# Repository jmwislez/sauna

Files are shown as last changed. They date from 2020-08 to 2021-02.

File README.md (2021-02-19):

# Building an outside sauna from scratch

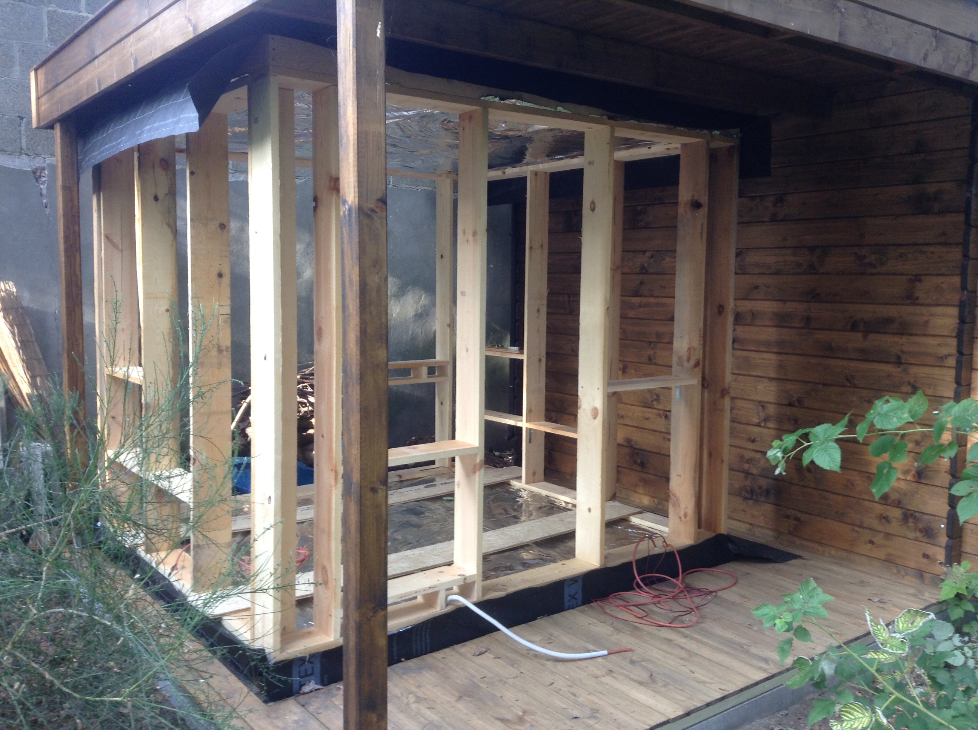
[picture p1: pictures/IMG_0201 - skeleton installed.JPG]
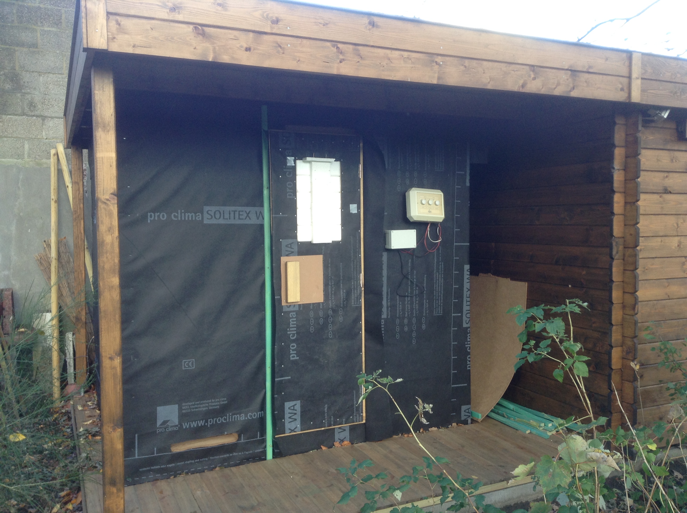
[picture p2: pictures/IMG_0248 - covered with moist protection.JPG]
  

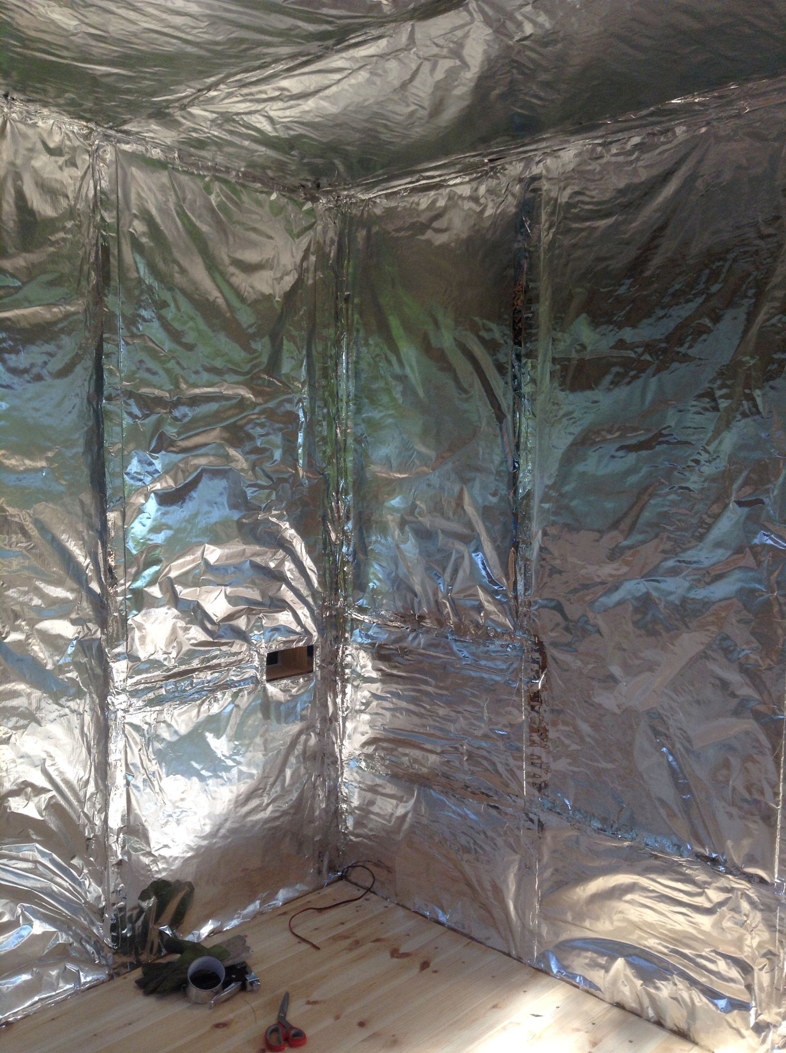
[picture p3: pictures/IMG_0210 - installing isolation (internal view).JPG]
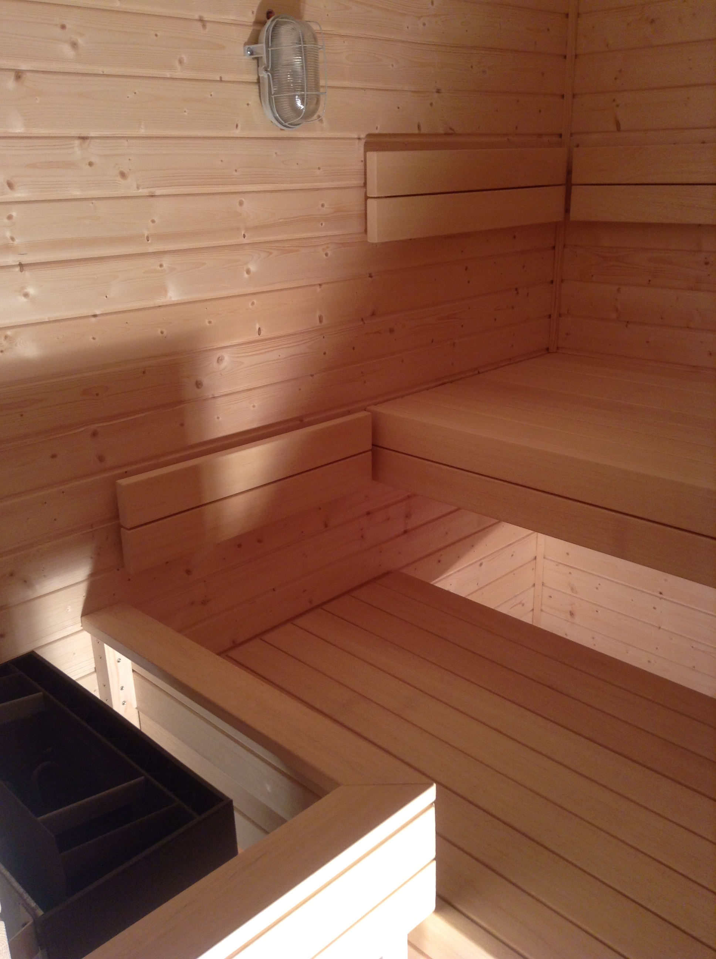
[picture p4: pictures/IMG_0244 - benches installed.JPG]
  

## What this repository provides

In this repository, you'll find a 3D design (FreeCAD) for an external sauna I built in 2013, as well as for an outside shower I added recently.  It also provides some materials and costs overviews for the sauna (2013 in Belgium), as well as snapshots of the design and pictures taken during building.  Through cost-effective procurement, I was able to limit the material costs to about 2000 euro.

## The layout and dimensions

The sauna was to be installed outside, under an existing 2.2m high 3x3m hood of a garden shed.  Hence, there is no roof as part of the sauna design. A stabilized platform was already available.  

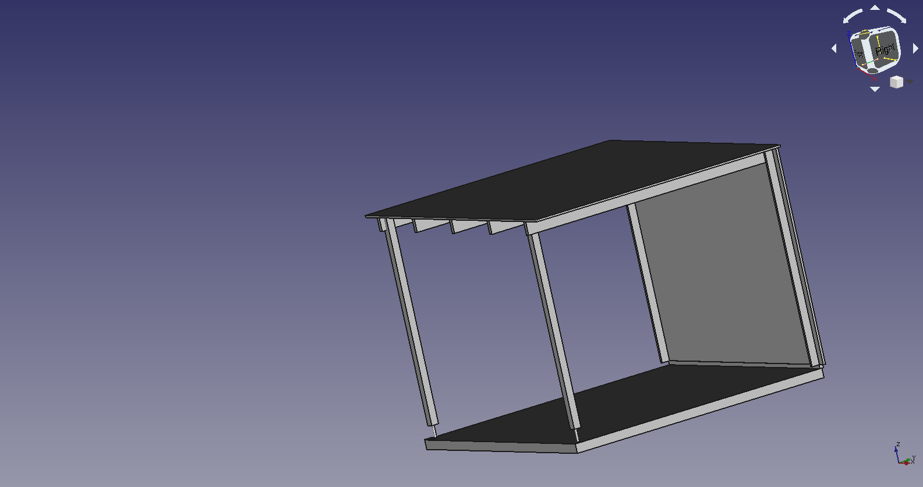
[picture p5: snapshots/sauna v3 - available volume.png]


The available volume under the hood was the main driving factor for the dimensions.  Within these limitations, I searched for an optimal layout with minimal inner dimensions (to reduce the volume and hence heating costs), and considering anthropometric dimensional data (95th percentile) for ergonomy.  The sizes were then fine-tuned to the available wood and materials sizes.  I am quite satisfied with the selected layout, as the sauna is comfortable and makes good use of the available space.

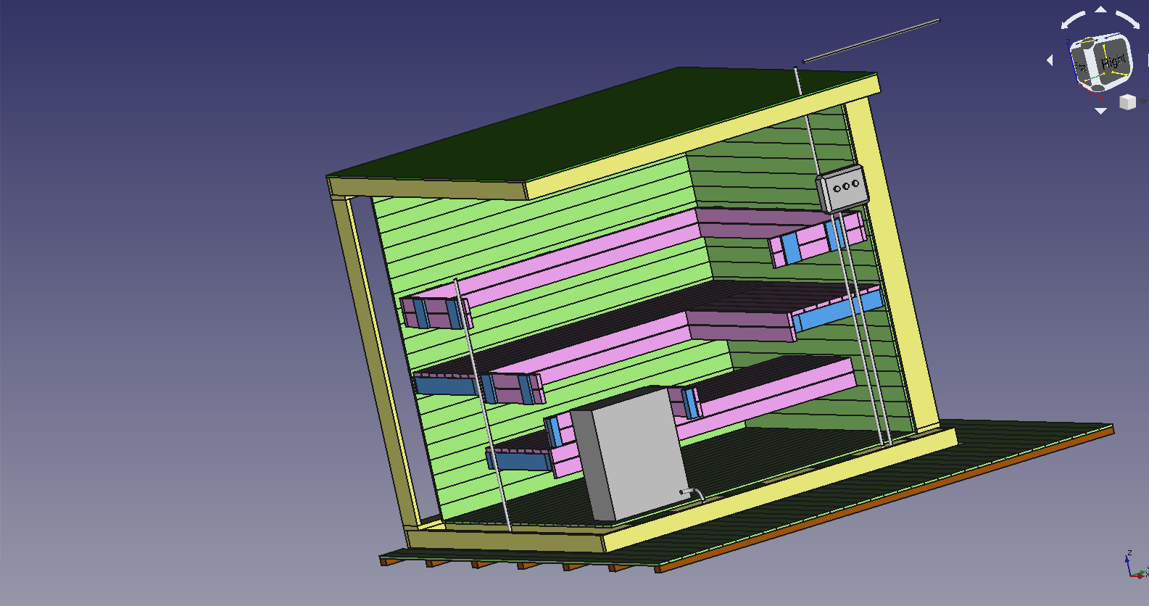
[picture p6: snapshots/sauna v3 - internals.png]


For the height, this meant one bench at 42cm height above the sauna floor (typical ergonomic sitting height), one at 84cm (to sit with feet on the lower bench), and then a sitting height of at least 100cm (95th percentile) between the top bench and the roof - I ended up at 104cm.  Given the limitation in the vertical space, I had to limit the floor and ceiling isolation thickness to 10cm only.  Total external height is 213cm, total internal height is 188cm.

For the internal width, I took 2m lying length (95th percentile), and for the depth 1.8m (50th percentile, and fine for me), which conveniently allowed me to have 3 standard-sized segments in both side walls.  What I forgot is to consider that two persons lying down will collide in the corner.  Hence, if you have room, take some extra margin.

The sauna is resting on the base beams of the terrace, to allow for air to circulate in the cavity in the walls, in order to keep them dry.

## Construction

The construction is based on a wood skeleton, with 58cm in between the beams (for fitting 60cm rockwool).  

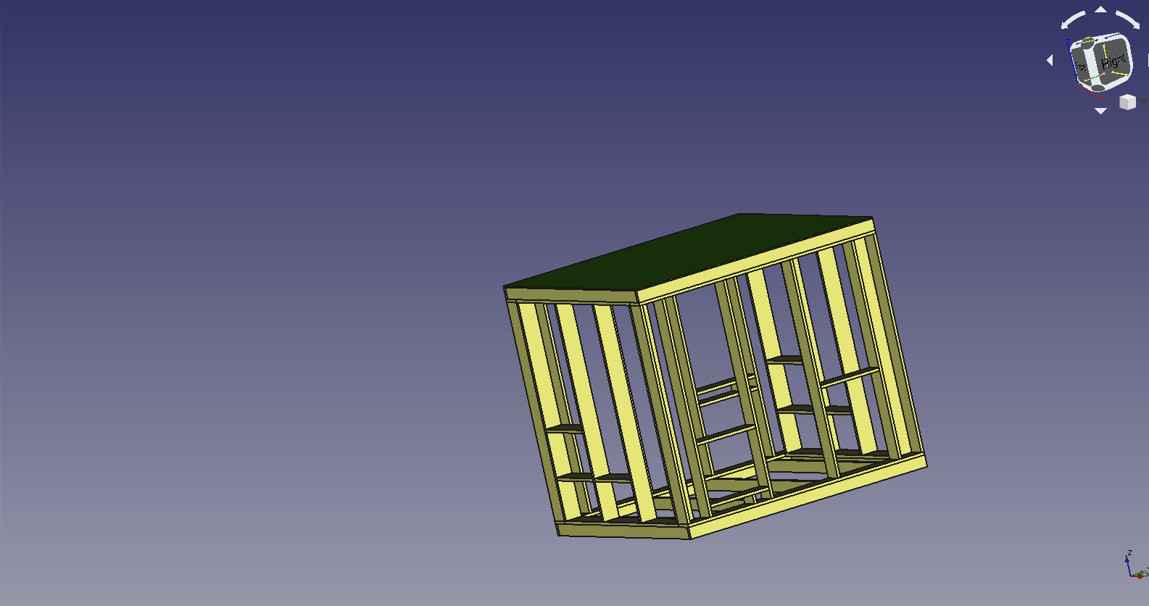
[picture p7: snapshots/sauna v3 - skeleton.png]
 
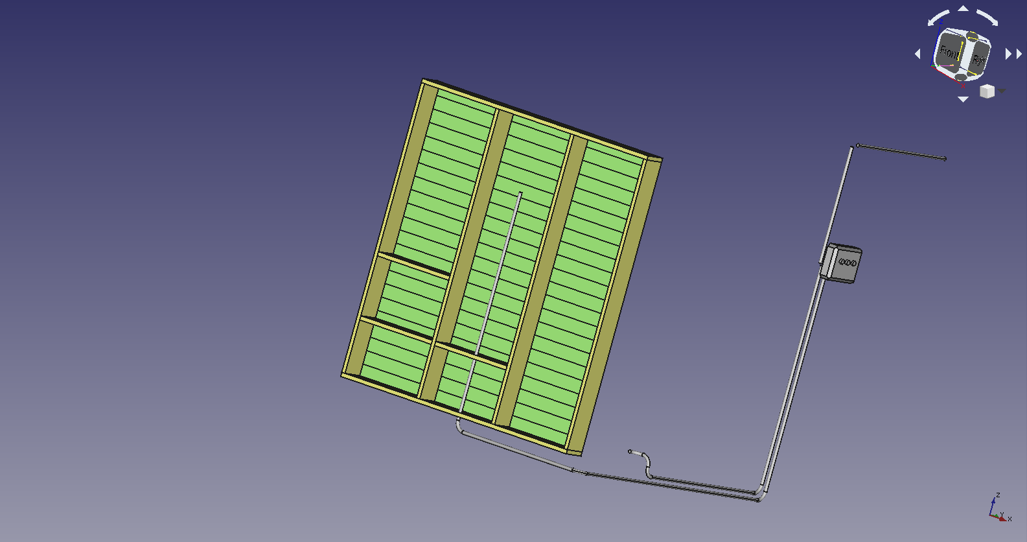
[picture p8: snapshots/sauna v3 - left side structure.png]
 
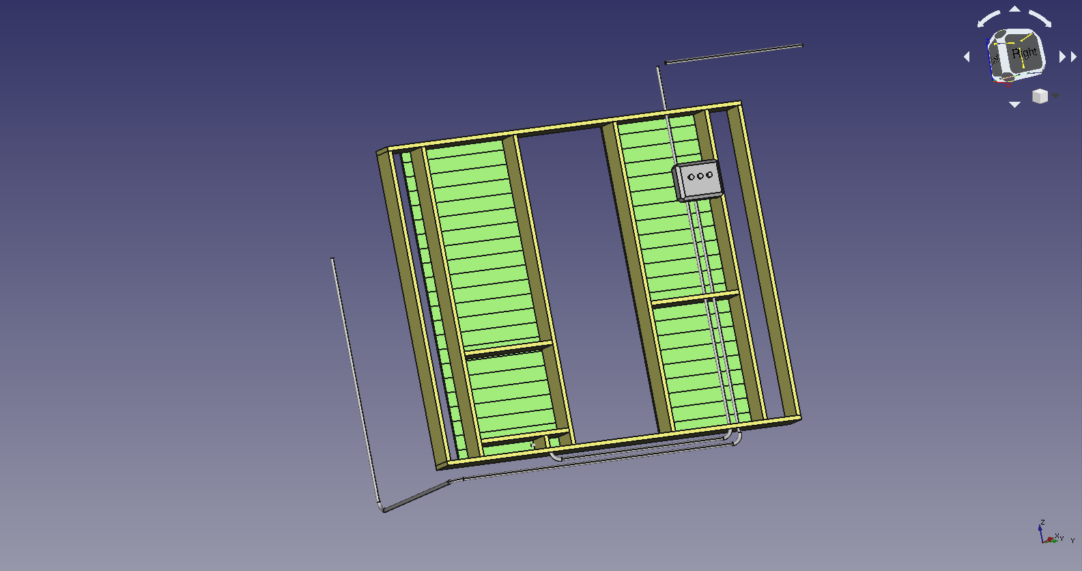
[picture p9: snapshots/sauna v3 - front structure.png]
 
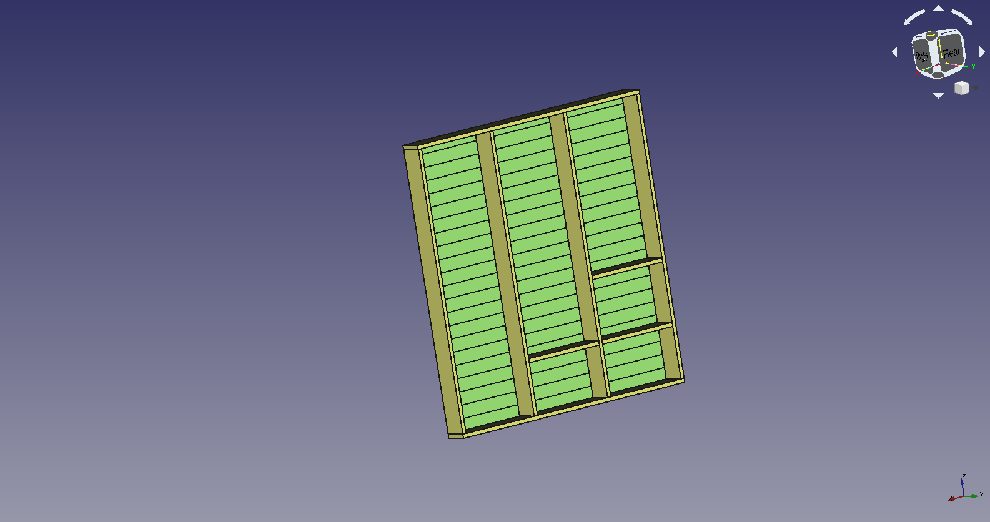
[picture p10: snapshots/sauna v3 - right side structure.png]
 
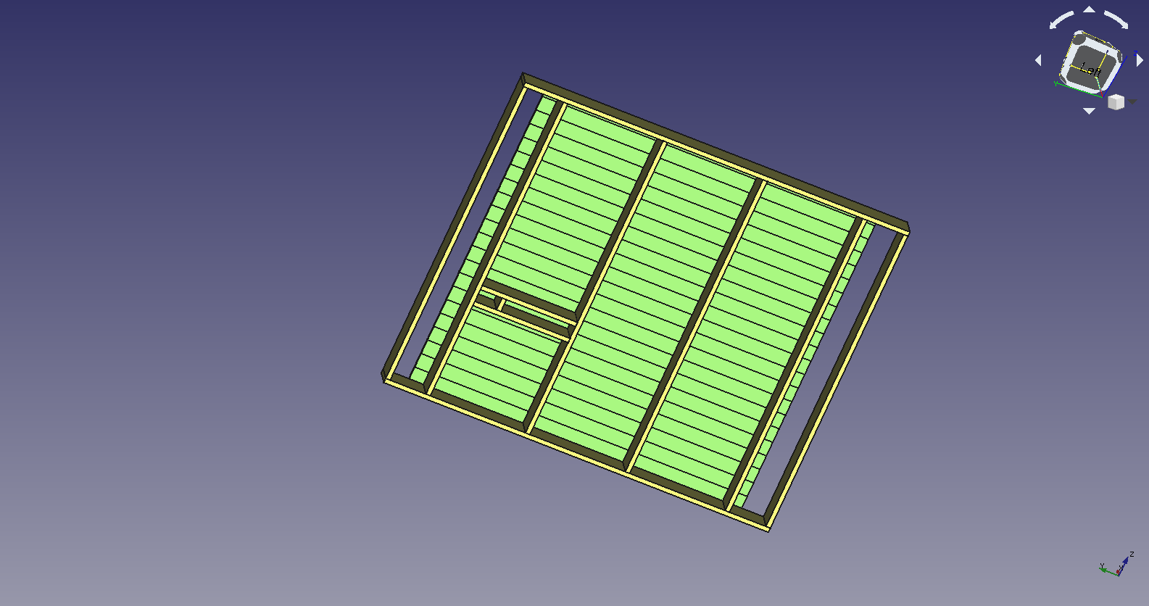
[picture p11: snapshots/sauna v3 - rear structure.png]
 
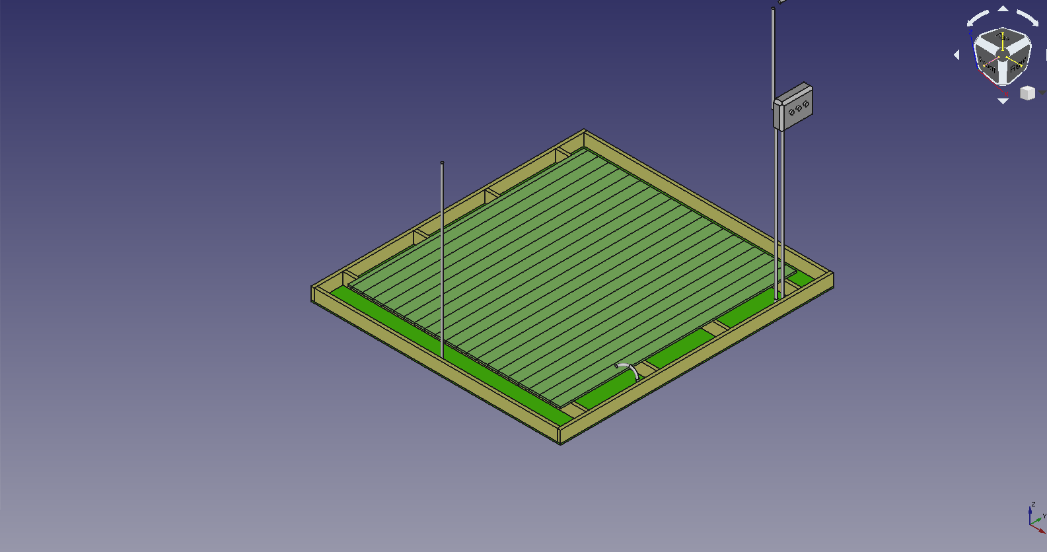
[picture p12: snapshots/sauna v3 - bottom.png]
 
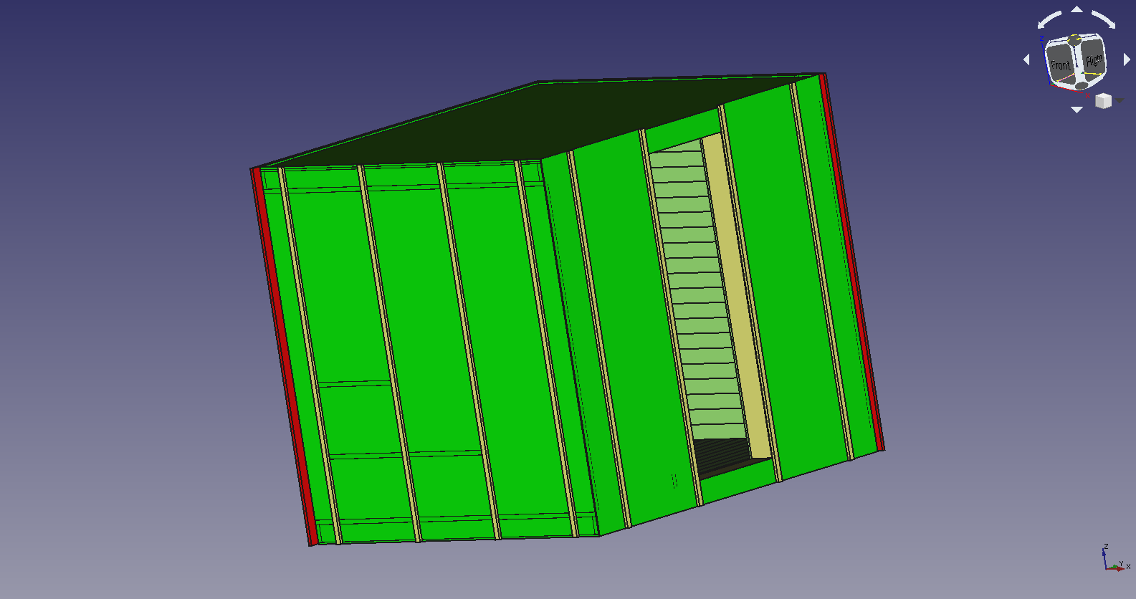
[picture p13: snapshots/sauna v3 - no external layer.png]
 
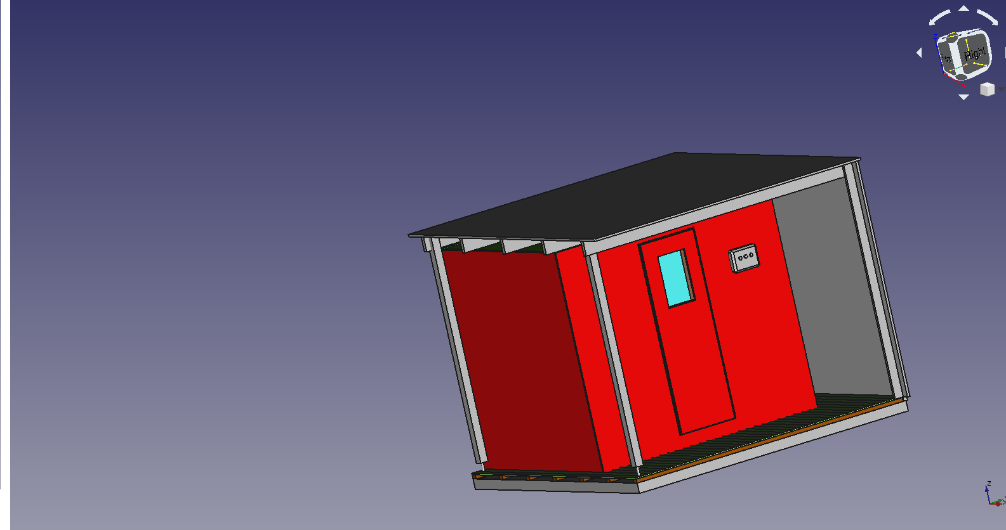
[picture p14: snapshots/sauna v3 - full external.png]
 

This was roughly the manufacturing and assembly sequence:
* Assembly of the terrace, with 7 parallel base beams, and tongue-and-groove planks around the area where the sauna will be installed (all treated with Xyladecor).
* Covering the area of where the sauna will be with 1cmx1cm chicken wire, against mice.
* In a workshop, assembly of the skeletons for all 6 faces of the sauna.
* In the workshop, full outfitting of the bottom and top skeletons with OSB plates, electrical tubing and wiring, and rockwool with reflective vapourshield. Also mounting of the vapour permeable breathable membrane on all wood sides.
* Positioning of the bottom assembly onto the terrace.
* Installation of the skeletons of the side walls.
* Installation of the top assembly onto the side walls.
* Oufitting of the side walls with rockwool, making the vapourshield airtight with aluminium tape (to the extent possible).
* Installation of electricity tubing and wiring in the side walls.
* Closing the side walls with MDF plates, being mindful of the external connections that need to be made (to sauna controller and audio amplifier).
* Wrapping the vapour permeable breathable membrane around the side walls, and fully attaching it with staples.
* Installing the floor wood, as wel as the inner walls (nordic pine sauna-wood - attached with mounting clips), being mindful of the internal connections that need to be made (to light, heater, heat sensor and speakers).
* Installing the skeletons for the benches.
* Installing the heater, sensor, and controller.
* Installing the abachi wood for the benches and backrests, and the heater protection.
* Installing the door (assembled in workshop).
* First heat for the sauna! :-)
* Installing the slating battens and the external wood finishing (treated with Xyladecor).

The walls are composed of the following layers (from inside to outside), totalling 21cm:
* Internal wood finishing, composed of 95mm x 14mm tongue-and-groove planks [NL: saunaschroten] (second choice nordic spruce, specially dried for use in sauna), attached with mounting clips [NL: profielhoutklemmen].
* Reflective vapourshield (integrated with the glasswool), finished with aluminium tape.
* 60cm wide 15cm thick glasswool (Isover) with integrated reflective vapourshield, carried by the wood skeleton.
* Thin MDF plates for covering the glasswool.
* Vapour permeable breathable membrane [NL: dampscherm] (Pro Clima SOLITEX WA).
* Air layer (slating battens as spacers [NL: panlatten]).
* External wood finishing, composed of second choice 170mm x 19mm tongue-and-groove planks [NL: schroten], treated for outdoor use with Xyladecor.

Just to be clear: these are the layers of the floor, from inside to outside: wooden floor, moist shield, rockwool, OSB, vapour breathing membrane, chicken wire, air, and then the concrete base of the garden shed. Same for the roof, where the vapour breathing membrane was mounted in tent shape under the roof of the garden shed, to deal with possible leakages in the garden shed roof.

The layer build-up is also visible in the building pictures.

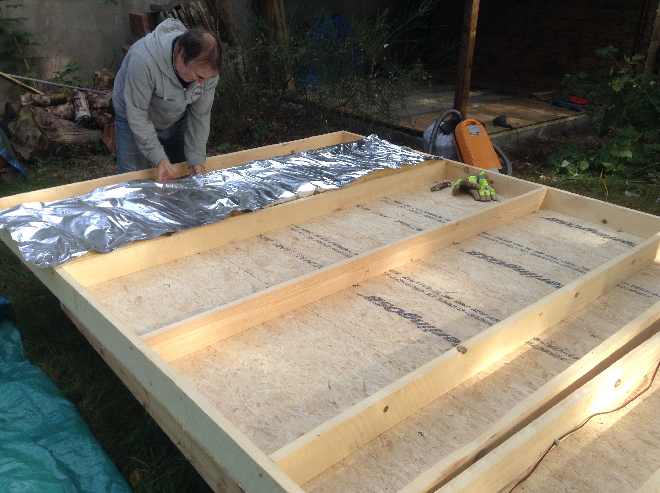
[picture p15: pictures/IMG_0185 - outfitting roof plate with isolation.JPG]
 
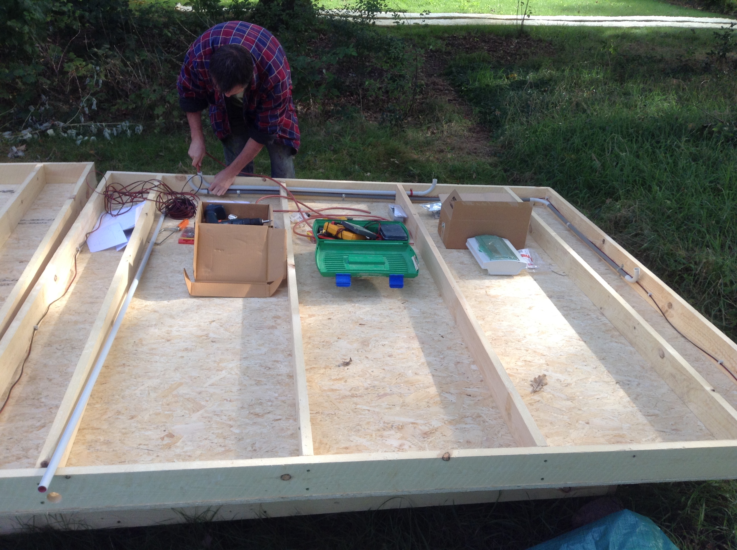
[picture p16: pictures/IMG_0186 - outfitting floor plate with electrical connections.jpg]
 
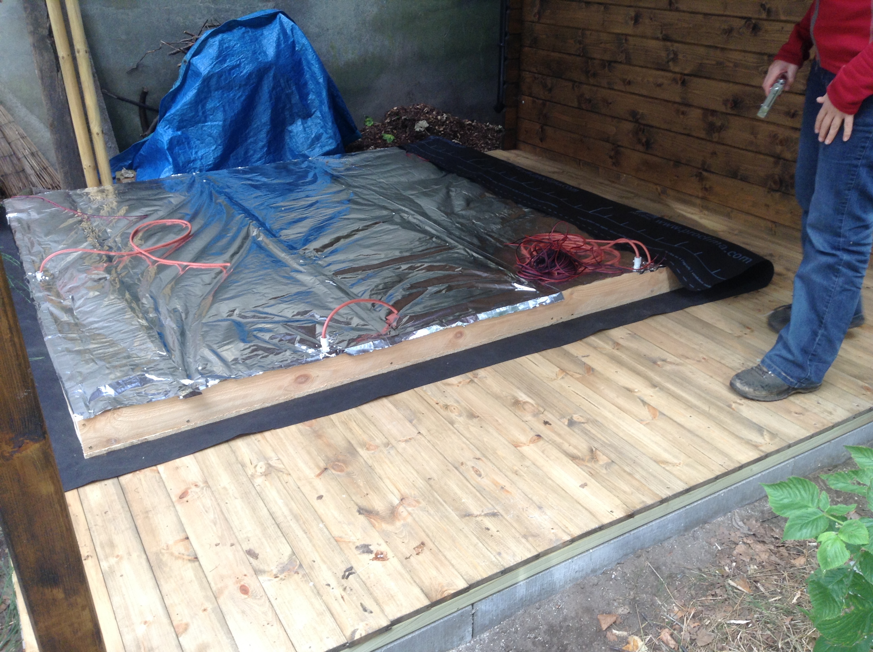
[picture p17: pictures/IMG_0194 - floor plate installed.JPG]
 
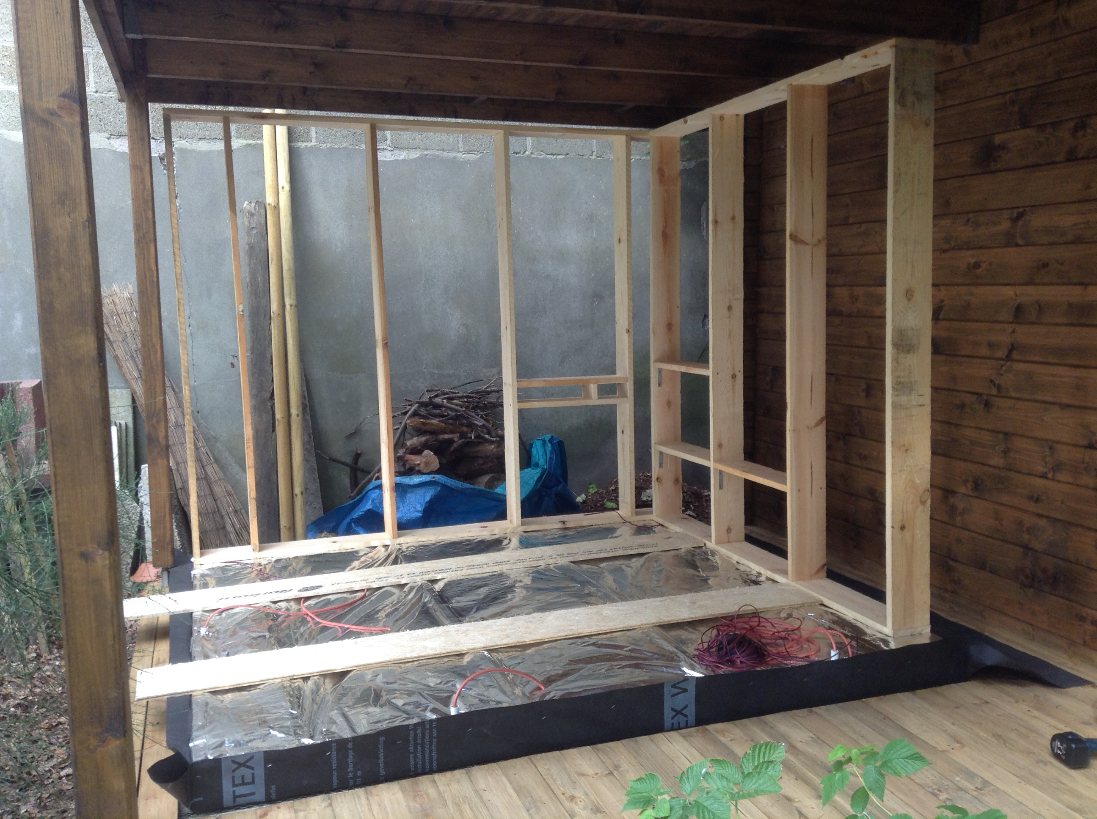
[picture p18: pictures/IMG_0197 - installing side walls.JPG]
 
 
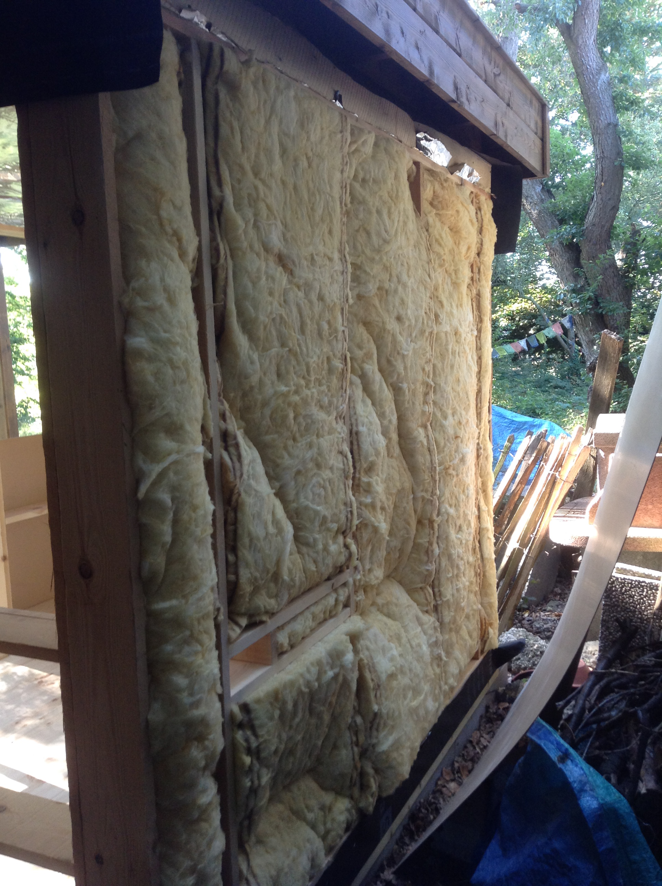
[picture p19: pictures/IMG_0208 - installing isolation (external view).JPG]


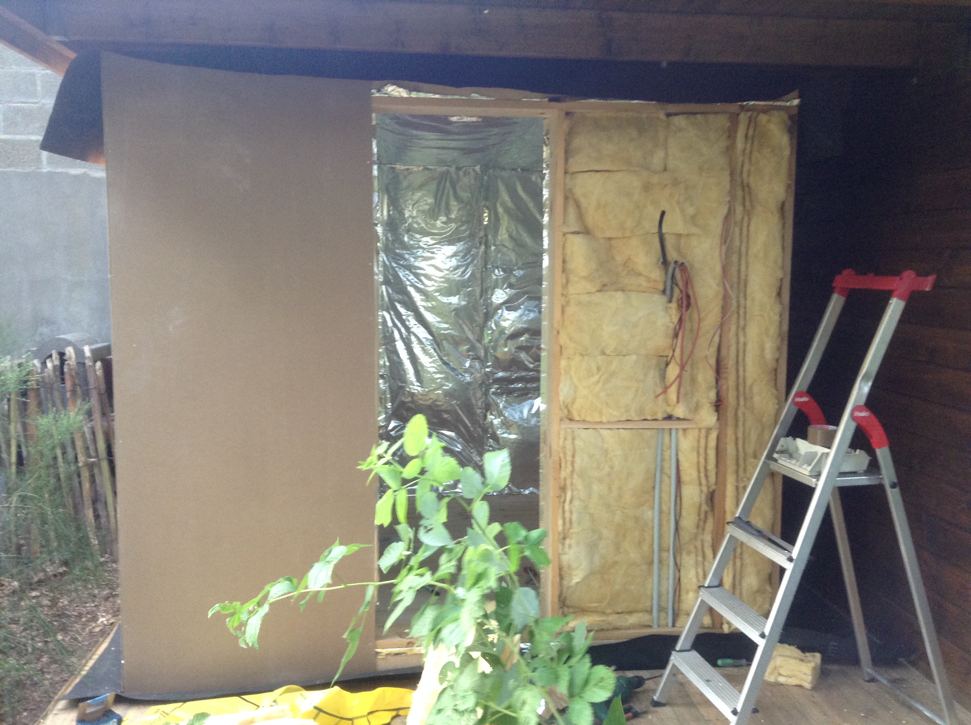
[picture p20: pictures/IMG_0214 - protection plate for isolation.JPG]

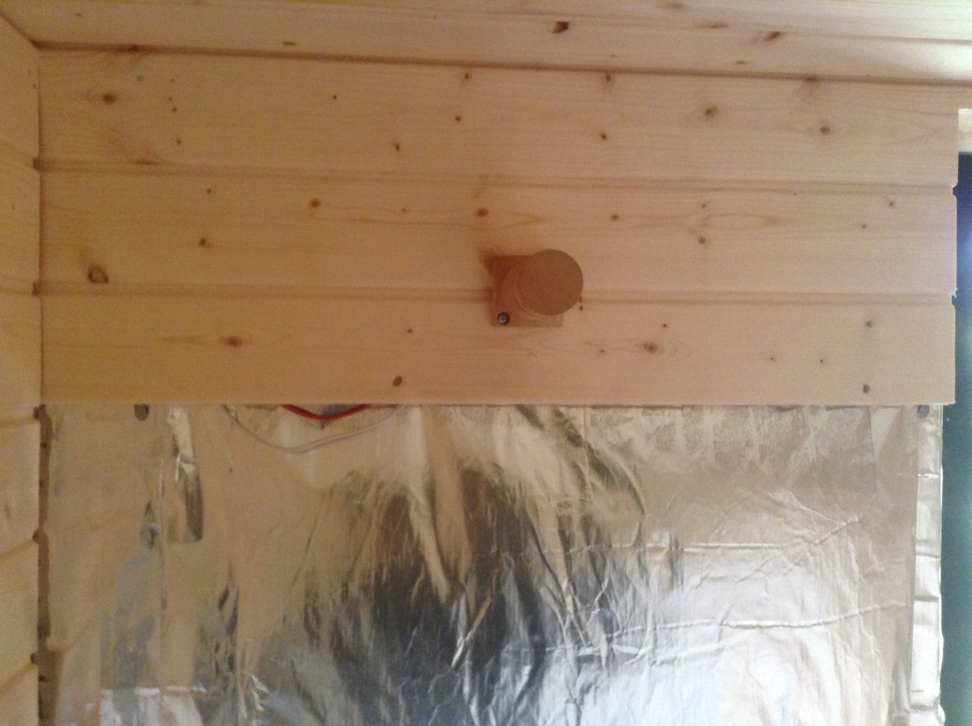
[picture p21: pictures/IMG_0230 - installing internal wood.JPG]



## Benches 

The benches are based on solid beams anchored to the main skeleton structure using big screws.  The benches are made of Abachi-wood.  This is an excellent choice, but be careful when working that wood: it generates a very fine dust which gives headaches that last for days.  Work outside, or with a good dust mask.

While 60cm width is enough for lying down, benches of 70cm are more comfortable. But for sitting down on a bench, 60cm is more comfortable than 70cm. This, and to limit the depth of the sauna, is why the lower bench extends 10cm under the top bench, and why the side bench is 60cm wide. 

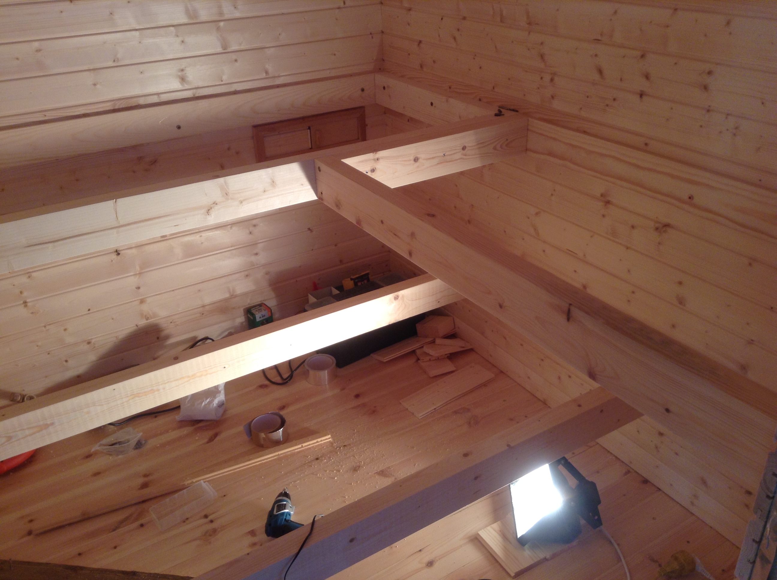
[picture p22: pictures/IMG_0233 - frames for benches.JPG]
 


## Door

TBW

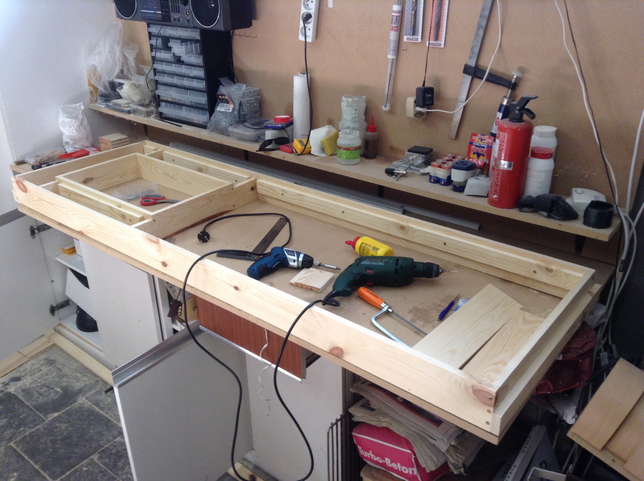
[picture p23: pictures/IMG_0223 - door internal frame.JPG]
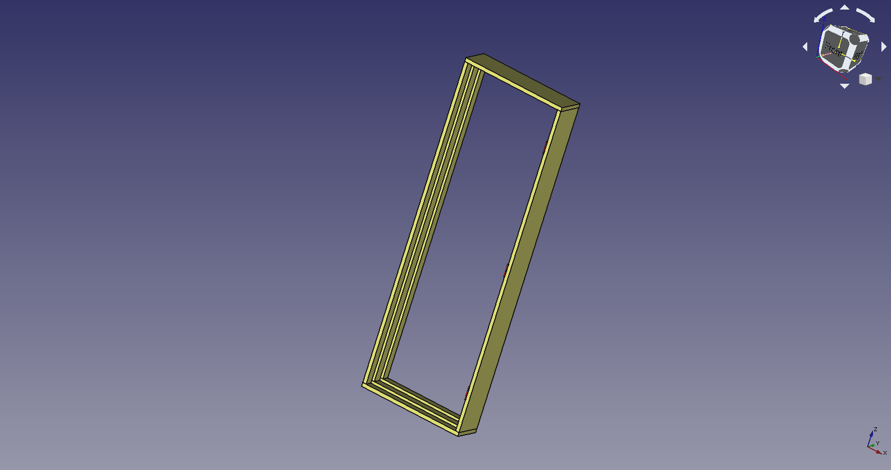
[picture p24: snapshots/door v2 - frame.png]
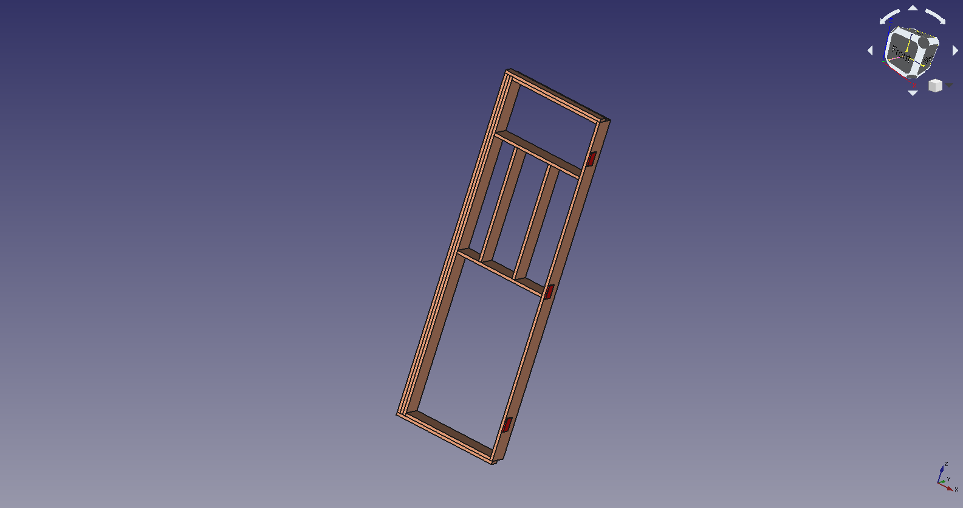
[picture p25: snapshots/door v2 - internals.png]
    

## The heating system

For 100 euro I bought a second hand 6 kW electric heater, a controller with sensor, a light, two headrests, a wooden bucket and a wooden spoon.

For a 6 kW heater (any heater above 4.5 kW), a three phase electricity installation is needed.  Check what is needed to do this legally and safely at your place.  I installed an underground EXVB 5G2.5mm2 cable in a red plastic tube at a depth of 60cm, which led to a separate fuse board with a 30mA differential fuse (sauna is a wet zone) and a 3-phase 16A overcurrent fuse.  The cables that led power into the sauna (for the heater and the light) was a SIHF cable given the heat endured in a sauna.

Be sure to include ventilation. Foresee a wide slit underneath the heater for air input, and an exit halfway the opposite wall.

## The shower

Given the absence of a sewer connection, the water needs to infiltrate into the ground.  Also, I wanted to be able to easily empty or lower the levels in the water pipes in and above the ground in case of frost.  Finally, I wanted to have the possibility for having sun-heated water.  All this ended up in a way too complex set of pipes and valves (as shown below), but it works!

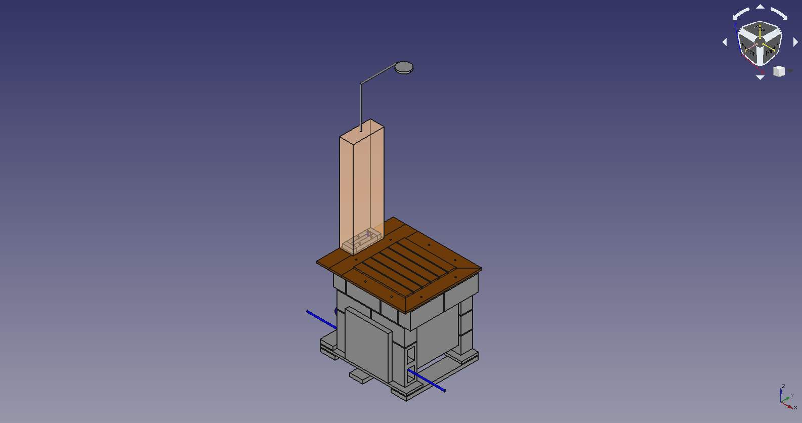
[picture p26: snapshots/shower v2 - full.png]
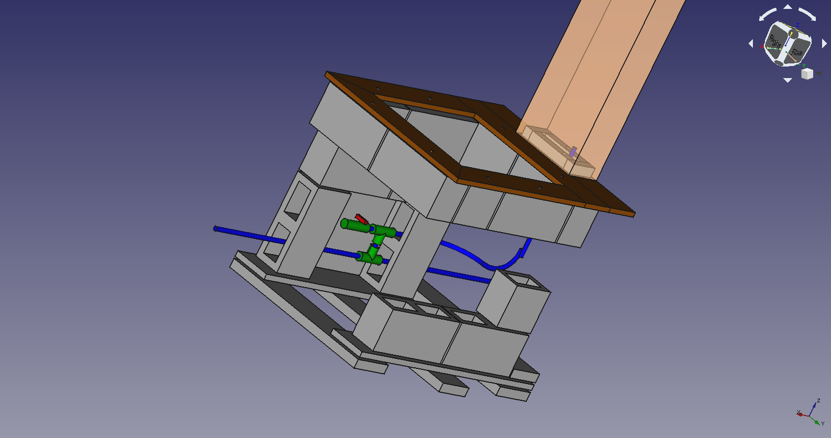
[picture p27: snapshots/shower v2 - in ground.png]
  

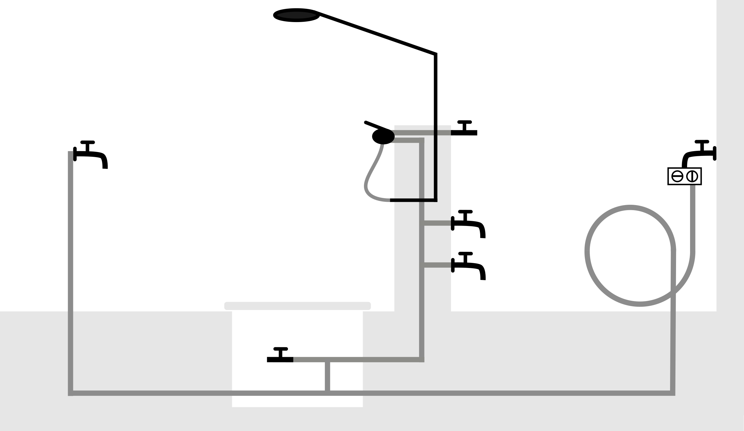
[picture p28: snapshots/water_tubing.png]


## Using the sauna

The sauna is comfortable for 2-3 people lying down, and can fit up to 6-7 people sitting.  

Heating at 6 kW takes about 45-60 minutes, after which the heater duty cycle is around 50%. An example profile is shown below.

  Temperature profile (degC)<br />
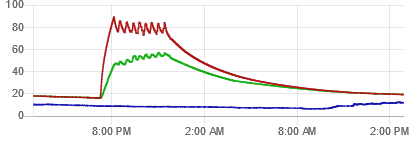
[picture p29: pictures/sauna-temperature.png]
  <br />
 
  Humidity profile (% RH)<br />
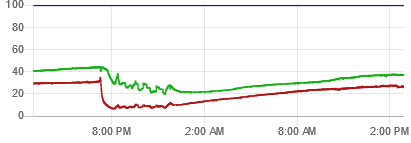
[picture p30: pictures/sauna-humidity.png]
  <br />

  Power consumption profile (W) (on top of other domestic use)<br />
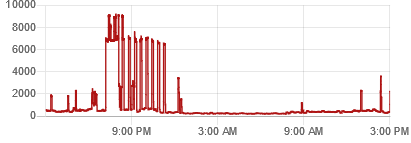
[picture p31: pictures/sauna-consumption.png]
  <br />

## Goodies

I installed old speakers at the bottom rear corners (coolest places), and outside I installed a watertight box with a car amplifier inside.  This way, I can connect an audio source with a 3.5mm stereo plug, and play music inside.

In an attempt to keep humidity as low as possible (not sure that it makes a real difference) I added an ESP8266-based controller, comparing internal and external absolute humidity (with DTH-22 sensors), and starting fans when the outside absolute humidity is lower.  In practice, this ventilation is only active when the sauna is heated.  Nice side effect is that I have temperature and humidity logging over MQTT, which I can monitor with Home Assistant.  The system can also warn me on my phone when the sauna is hot.  

I also attempted to have a "bio-sauna" effect by using a WiFi-controlled RGB LED-bulb, with colour settings controlled by the ESP8266.  This worked well in development (even have a nice mode with the bulb colour going from blue to red while the sauna is heating), but in practice the WiFi connection of the bulb is unstable when the sauna temperature is high, making a proper control impossible.

## What I would do differently

* If room is available, increase the isolation thickness everywhere to 20cm.
* I would make the sauna slightly wider, to avoid legs colliding when 2 people are lying down on the top benches.
* The side top bench is now 60cm wide, but 70cm would be even more comfortable.
* The wooden door is nice, but throughout seasons it needs retuning to close well and open easily.
* After I applied the outer wood layer (one year later), I found out the door would not open further than 90 degrees any more.
* In order to limit the volume of the sauna (and thus improving heating time and reducing power consumption), the volume under the benches could be sealed off.  This volume is anyway totally lost, and in my case only used for rarely used speakers.  Only the ventilation outlet should then be moved above the benches. 



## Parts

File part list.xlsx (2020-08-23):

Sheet: Part list
Name | Size | Qty | Function | Assembly
Floor structure
Rough pine beam (A) | 2330mm x 100mm x 27mm | 2 | Structure | assembled with screws
Rough pine beam (B) | 2075mm x 100mm x 27mm | 6 | Structure | assembled with screws
OSB plate | 2330mm x 2130mm x 12mm | 1 | Structure | assembled with screws
Pro Clima SOLITEX WA | 2700mm x 2500mm | 1 | Humidity protection | fixated with stapples
Rockwool | 2075mm x 600mm x 100mm | 3 | Isolation | fixated with stapples and aluminium tape
Rockwool | 2075mm x 220mm x 100mm | 2 | Isolation | fixated with stapples and aluminium tape
Pine tongue and groove plank | 2014mm x 89mm x 15mm | 21 | Internal finish | assembled with screws
Chicken wire (1cm maze) | 2700mm x 2500mm | 1 | Protection against mice
Rear wall structure
Rough pine beam (I) | 2330mm x 153mm x 27mm | 2 | Structure | assembled with screws
Rough pine beam (G) | 1855mm x 153mm x 27mm | 6 | Structure | assembled with screws
Rough pine beam (M) | 578mm x 153mm x 27mm | 2 | Structure / ventilation exit hole | assembled with screws
Rough pine beam (AH) | 75mm x 153mm x 27mm | 1 | Structure / ventilation exit hole | assembled with screws
Nordic pine tongue and groove sauna plank | 2014mm x 86mm x 15mm | 22 | Internal finish | attached with mounting clips / cut-out for ventilation exit
Rockwool | 1855mm x 600mm x 150mm | 3 | Isolation | fixated with stapples and aluminium tape / cutouts as needed
Rockwool | 1855mm x 220mm x 150mm | 2 | Isolation | fixated with stapples and aluminium tape
MDF plate | 2330mm x 2145mm x 4mm | 1 | Contain Rockwool | fixated with nails
Pro Clima SOLITEX WA | 2400mm x 1900mm | 1 | Humidity protection | fixated with stapples / all side walls at once
Battens | 2145mm x 32mm x 18mm | 4 | Spacer behind external cover | fixated with screws
Pine tongue and groove plank | 2409mm x 160mm x 19mm | 13 | External finish | assembled with screws / protected with Xyladecor
Left wall structure
Rough pine beam (F) | 1824mm x 153mm x 27mm | 2 | Structure | assembled with screws
Rough pine beam (G) | 1855mm x 153mm x 27mm | 4 | Structure | assembled with screws
Rough pine beam (M) | 578mm x 153mm x 27mm | 3 | Structure / bench support | assembled with screws
Nordic pine tongue and groove sauna plank | 1790mm x 86mm x 15mm | 22 | Internal finish | attached with mounting clips / cut-out for ventilation exit
Rockwool | 1855mm x 600mm x 150mm | 3 | Isolation | fixated with stapples and aluminium tape / cutouts as needed
MDF plate | 2130mm x 2145mm x 4mm | 1 | Contain Rockwool | fixated with nails
Pro Clima SOLITEX WA | 1900mm x 1900mm | 1 | Humidity protection | fixated with stapples / all side walls at once
Battens | 2145mm x 32mm x 18mm | 4 | Spacer behind external cover | fixated with screws
Pine tongue and groove plank | 2172mm x 160mm x 19mm | 13 | External finish | assembled with screws / protected with Xyladecor
Right wall structure
Rough pine beam (F) | 1824mm x 153mm x 27mm | 2 | Structure | assembled with screws
Rough pine beam (G) | 1855mm x 153mm x 27mm | 4 | Structure | assembled with screws
Rough pine beam (M) | 578mm x 153mm x 27mm | 3 | Structure / bench support | assembled with screws
Nordic pine tongue and groove sauna plank | 1790mm x 86mm x 15mm | 22 | Internal finish | attached with mounting clips / cut-out for ventilation exit
Rockwool | 1855mm x 600mm x 150mm | 3 | Isolation | fixated with stapples and aluminium tape / cutouts as needed
MDF plate | 2130mm x 2145mm x 4mm | 1 | Contain Rockwool | fixated with nails
Pro Clima SOLITEX WA | 1900mm x 1900mm | 1 | Humidity protection | fixated with stapples / all side walls at once
Battens | 2145mm x 32mm x 18mm | 4 | Spacer behind external cover | fixated with screws
Pine tongue and groove plank | 2172mm x 160mm x 19mm | 13 | External finish | assembled with screws / protected with Xyladecor
Front wall structure
Rough pine beam (I) | 2330mm x 153mm x 27mm | 2 | Structure | assembled with screws
Rough pine beam (G) | 1855mm x 153mm x 27mm | 6 | Structure | assembled with screws
Rough pine beam (M) | 578mm x 153mm x 27mm | 3 | Structure / bench+heater supports | assembled with screws
Rough pine beam (AH) | 75mm x 153mm x 27mm | 1 | Structure / ventilation entry hole | assembled with screws
Nordic pine tongue and groove sauna plank | 692mm x 86mm x 15mm | 44 | Internal finish | attached with mounting clips / cut-out for ventilation entry
Rockwool | 1855mm x 600mm x 150mm | 2 | Isolation | fixated with stapples and aluminium tape / cutouts as needed
Rockwool | 1855mm x 190mm x 150mm | 2 | Isolation | fixated with stapples and aluminium tape
MDF plate | 2145mm x 850mm x 4mm | 2 | Contain Rockwool | fixated with nails
MDF plate | 630mm x 138mm x 4mm | 2 |  | fixated with nails
Pro Clima SOLITEX WA | 750mm x 1900mm | 2 | Humidity protection | fixated with stapples / all side walls at once
Battens | 2145mm x 32mm x 18mm | 4 | Spacer behind external cover | fixated with screws
Pine tongue and groove plank | 2409mm x 160mm x 19mm | 2 | External finish | assembled with screws / protected with Xyladecor
Pine tongue and groove plank | 890mm x 160mm x 19mm | 22 | External finish | assembled with screws / protected with Xyladecor
Ceiling structure
Rough pine beam (A) | 2330mm x 100mm x 27mm | 2 | Structure | assembled with screws
Rough pine beam (B) | 2075mm x 100mm x 27mm | 6 | Structure | assembled with screws
OSB plate | 2330mm x 2130mm x 12mm | 1 | Structure | assembled with screws
Rockwool | 2075mm x 600mm x 100mm | 3 | Isolation | fixated with stapples and aluminium tape
Rockwool | 2075mm x 220mm x 100mm | 2 | Isolation | fixated with stapples and aluminium tape
Nordic pine tongue and groove sauna plank | 2014mm x 86mm x 15mm | 22 | Internal finish | attached with mounting clips
Pro Clima SOLITEX WA | 2700mm x 2500mm | 1 | Humidity protection | fixated with stapples
Doorframe (TBW)
Door (TBW)
Top bench (TBW)
Lower bench (TBW)
Heater protection (TBW)
Electricity (TBW)

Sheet: Main procurements
Sauna-heater + accessories | 2ehands.be | 100.00 €
Wood (structure) | Gijsbrechts n.v. | 306.31 €
OSB-plates | Woodtex | 60.72 €
Sauna wood (second choice) | saunahaus.com | 372.30 €
Base beams terrace | Woodtex | 15.00 €
Slating battens | Gamma | 16.06 €
External wood (second choice) | Bofa nv | 129.60 €
2x 12m glasswool 60cm/10cm | Iso-Technics | 58.00 €
4x 8m glasswool 60cm/15cm | Iso-Technics | 104.00 €
Thermally hardened glas | Dirk Walschaerts bvba | 34.10 €
Pro Clima SOLITEX WA | energie-shop.net | 60.00 €
Electricity | NV J. Piscaer | 351.53 €
Small items and consumables |  | 379.79 €
TOTAL |  | 1987.41 €

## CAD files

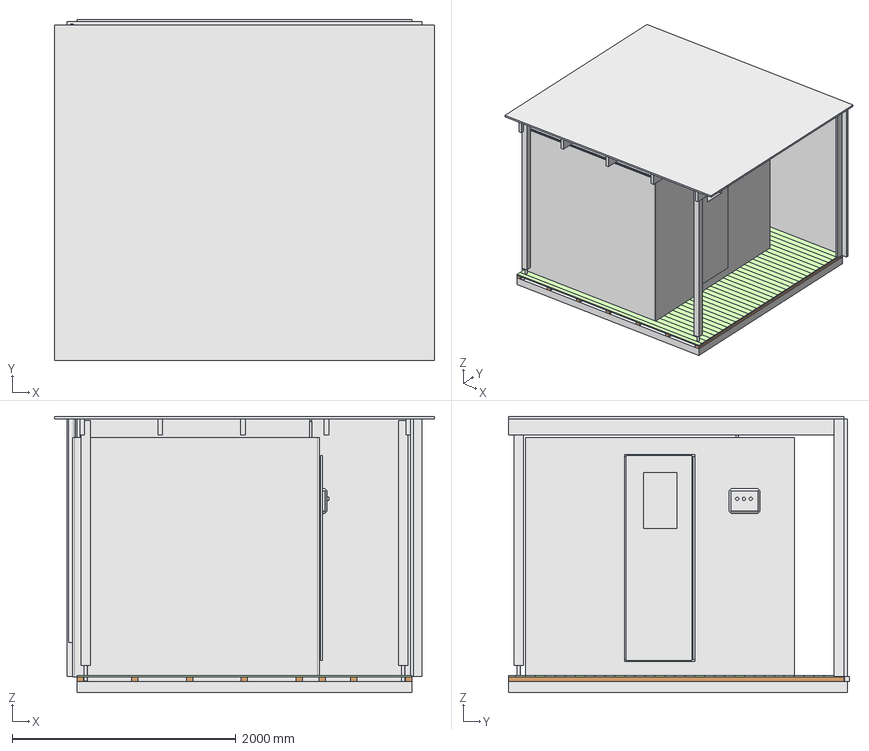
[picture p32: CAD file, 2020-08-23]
sauna v3.FCStd
3400.0 x 3049.0 x 2470.0 mm
Concrete base
Wall
Wall001
Wall002
Roof beam
Pole base
Pole
Pole support
Rainpipe
Roof
Roof beam001
Roof beam002
Roof beam003
Roof beam004
Pole support001
Pole001
Wall base
Terrasbalk001
Terrasbalk002
Terrasbalk003
Terrasplank001
Terrasplank002
TerrasplankA001
TerrasplankA002
TerrasplankA003
TerrasplankA004
TerrasplankA005
TerrasplankA006
TerrasplankA007
TerrasplankA008
TerrasplankA009
TerrasplankA010
TerrasplankA011
TerrasplankA012
TerrasplankA013
TerrasplankA014
TerrasplankA015
TerrasplankA016
TerrasplankA017
TerrasplankA018
TerrasplankA019
TerrasplankA020
TerrasplankA021
TerrasplankA022
TerrasplankA023
TerrasplankA024
TerrasplankA025
TerrasplankA026
TerrasplankA027
Terrasplank003
Terrasplank004
Terrasplank005
Terrasplank006
Terrasplank007
Terrasbalk004
Terrasbalk005
Terrasbalk006
Terrasbalk007
Terrasbalk008
Skeleton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

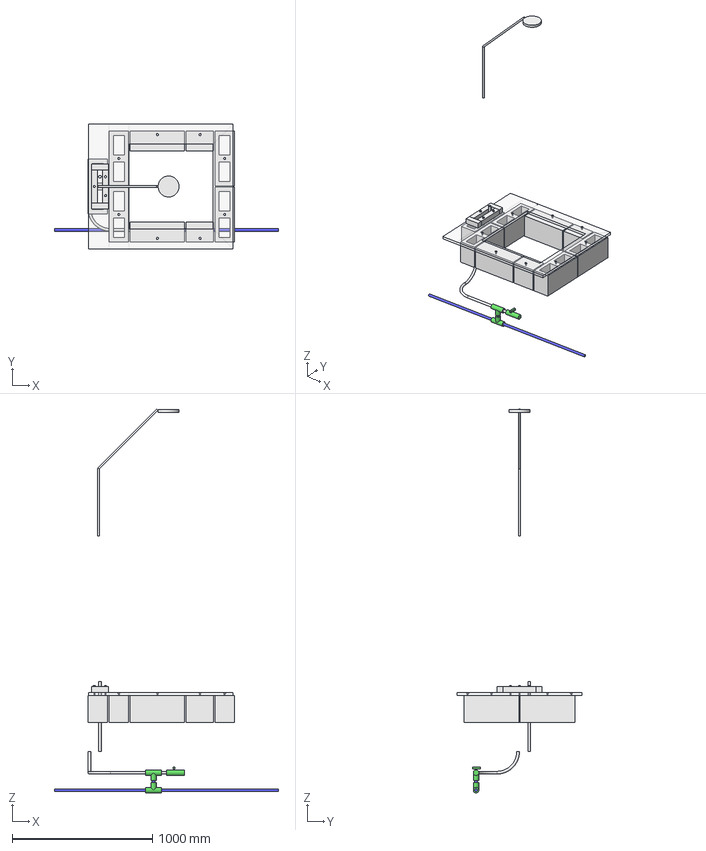
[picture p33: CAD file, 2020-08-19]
shower v2.FCStd
1600.0 x 890.0 x 2740.9 mm
douchebuis
douchebuis001
douchekop
T-stuk
T-stuk001
tyleen huis-yurt
kraan
tyleen douche
tyleen
snelbouwsteen (2x)009
plankenwerk
snelbouwsteen (2x)011
snelbouwsteen (2x)012
snelbouwsteen (2x)013
snelbouwsteen (2x)014
snelbouwsteen (2x)015
snelbouwsteen (2x)016
halve snelbouwsteen002
halve snelbouwsteen003
M8x10
M8x10 (2)
M8x10 (2)001
M8x011
M8x012
M8x013
M8x014
M8x015
M8x016
M8x017
M8x018

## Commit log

2020-08-19 Added all 3D models
    [buitendouche.FCStd, douchesokkel v2.FCStd, sauna v3.FCStd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]
2020-08-22 Rename dutch filenames to english
    [buitendouche.FCStd, saunadoor v2.FCStd, shower v2.FCStd]
2020-08-23 Cleaned up 3D model, and added part list and costing overview
    [part list.xlsx, saunadoor v2.FCStd]
